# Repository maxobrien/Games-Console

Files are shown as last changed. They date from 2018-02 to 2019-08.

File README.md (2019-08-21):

# Games Console Project - Max O'Brien
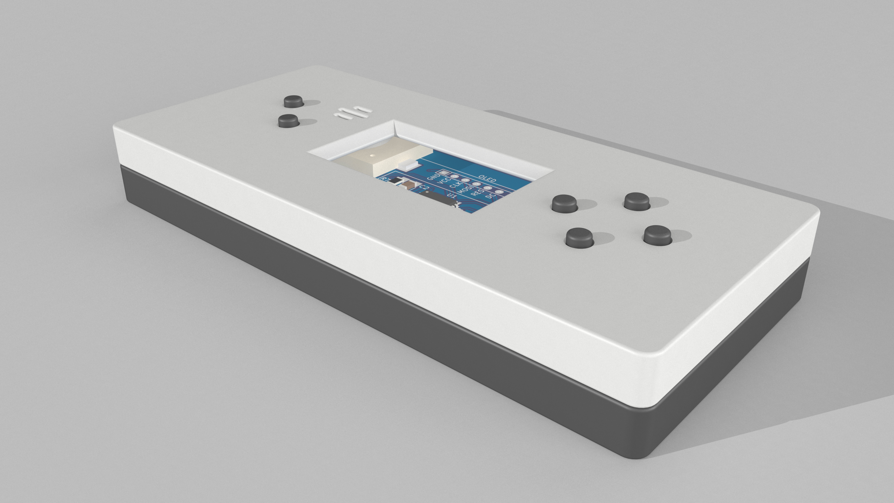
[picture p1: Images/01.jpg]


Above are all the files for my games console project.

## PCB Design Files
The PCB was originally designed in <a href="http://kicad-pcb.org/">KiCad 4.0.7</a> however other versions may still be able to open it. The board is a 2-layered design that can easily be manufactured at most places if that is what you wish to do.

**UPDATE** As of KiCad version 5.0 the board can still be opened however, you will need to run the automatic schematic symbol converter.

## STL Files
These files are for the enclosure of the games console. They fit the PCB supplied and so would need to be changed if you changed the dimensions of the board. If you are making your own then they can just be printed on a normal 3D printer, however, I would suggest you choose settings, and material, that will yield the highest quality detail as some of the model contains fine details. I chose black and white (as seen in the above render) and also printed it in SLS nylon.

## The Code
The code is written in the Arduino IDE. This means to open it, you will need the <a href="https://www.arduino.cc/en/Main/Software">Arduino IDE</a>. Before loading the code onto the micro, you will first have to burn a bootloader. Some guides to do this are listed below, however, doing your own research may yield better results.

- https://www.arduino.cc/en/Hacking/Bootloader
- https://learn.adafruit.com/ftdi-friend/programming-the-arduino-bootloader
- http://www.gammon.com.au/breadboard

Once the bootloader has be burned, you can upload the code. To do this, ensure your programmer is connected with a USB cable and open up the code in the Arduino IDE. Also ensure that the programmer is correctly connected to the programming header (Bottom Left) on the PCB. Check that all 5 tabs can be seen along the top labelled; "Main", "Breakout", "Menu", "pong" and "Settings". Next go to 'Tools > Board' and ensure 'Arduino/Genuino Uno' is selected. Then go to 'Tools > Port' and select the right port for your programmer. Finally, select 'Sketch > Upload Using Programmer'. Once this operation is complete, you should have a working games console!

## Console Renders
<details>
  <summary>Click to show renders</summary>
  
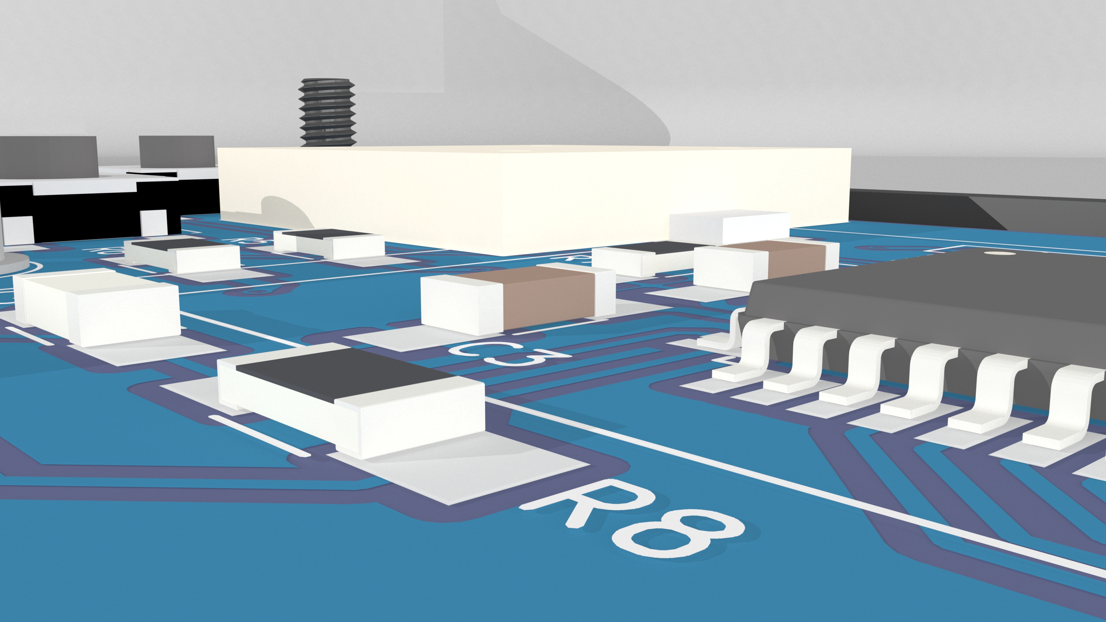
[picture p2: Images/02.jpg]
  
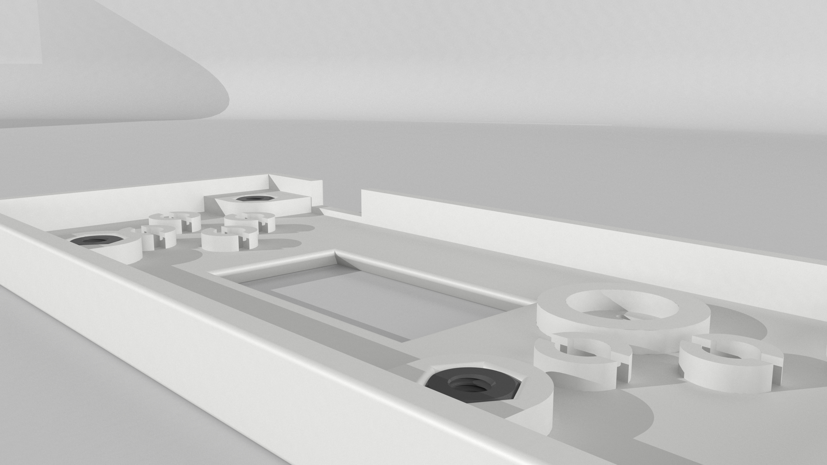
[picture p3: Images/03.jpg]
  
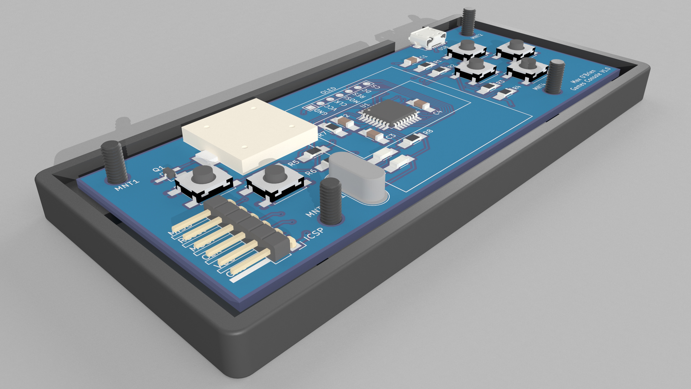
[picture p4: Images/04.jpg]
  
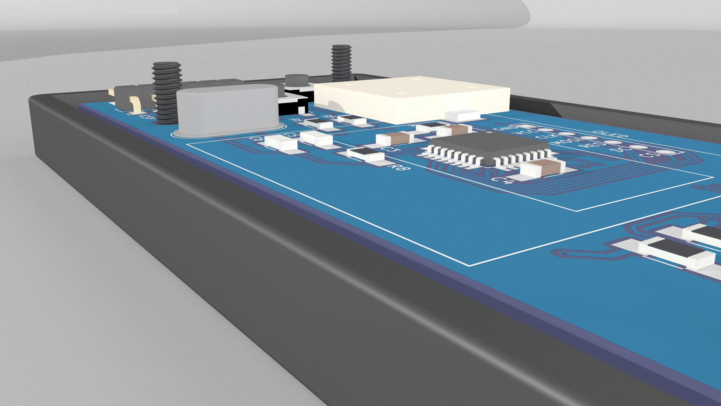
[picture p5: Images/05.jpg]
  
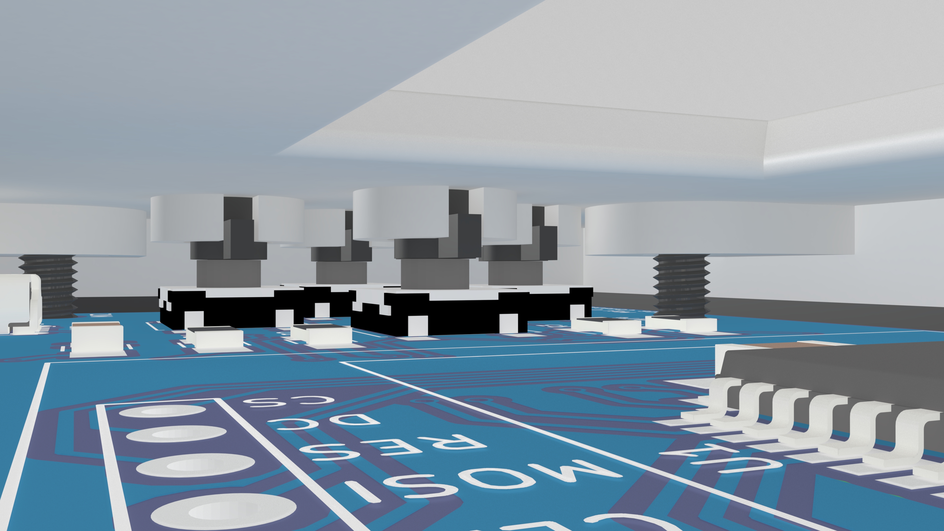
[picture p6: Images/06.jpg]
  
</details>

## Required Libraries for Code
- U8g2

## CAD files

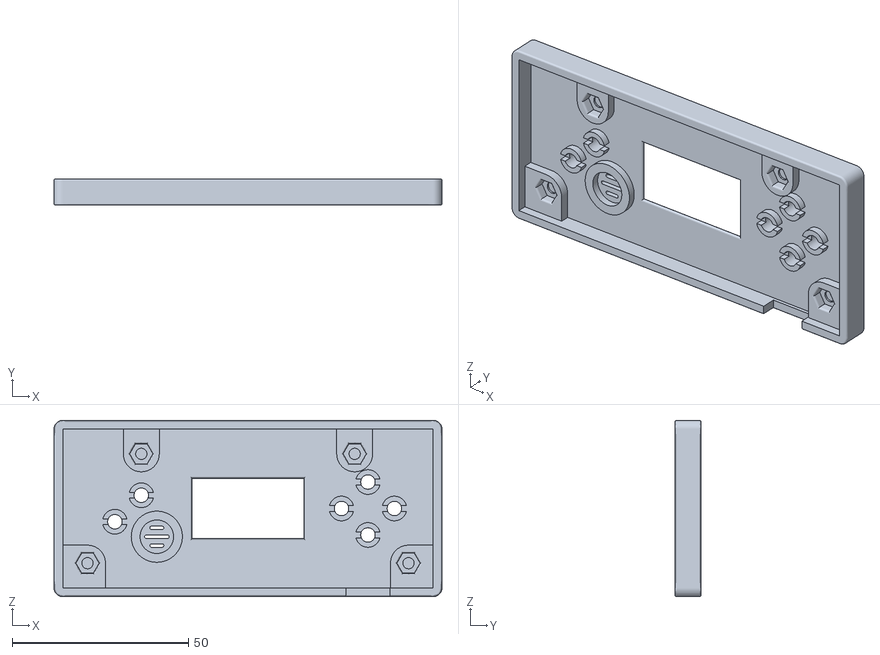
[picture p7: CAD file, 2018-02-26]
STL/Top (White).stl
110.0 x 7.50 x 50.0

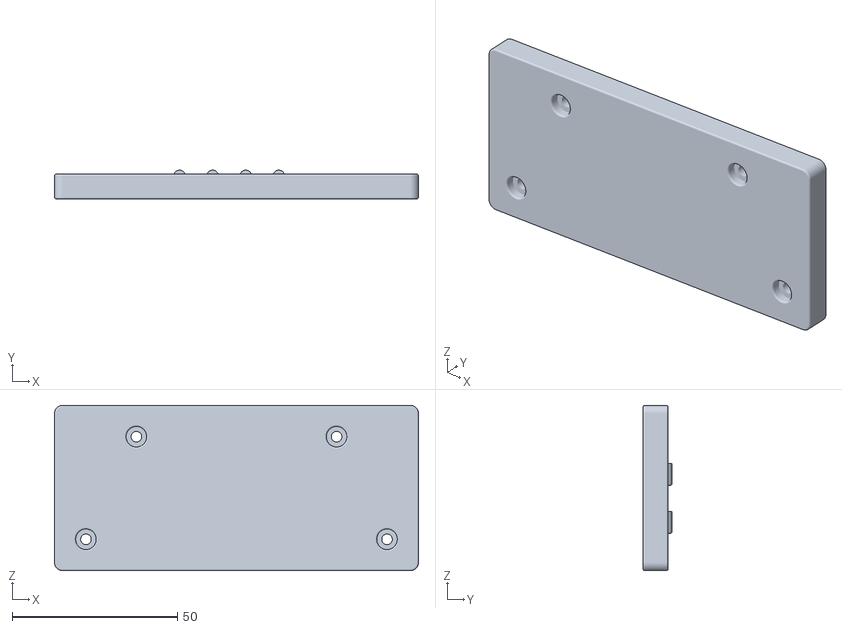
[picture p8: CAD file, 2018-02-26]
STL/Base and Buttons (Black).stl
110.0 x 8.70 x 50.0

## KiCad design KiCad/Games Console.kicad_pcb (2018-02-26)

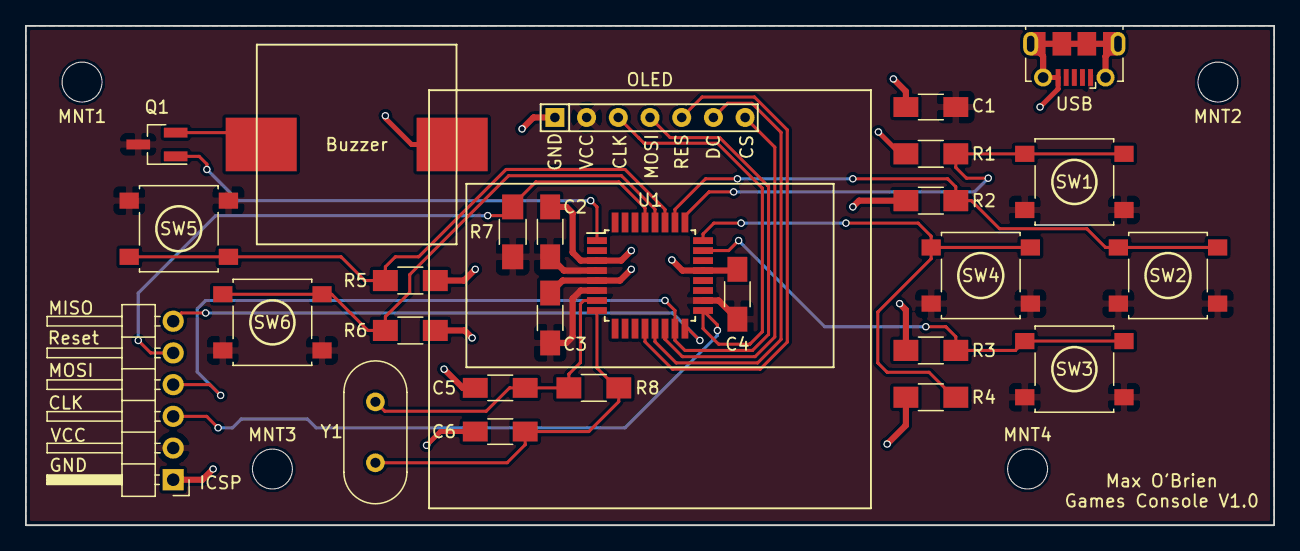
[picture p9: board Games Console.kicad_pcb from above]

Board: 2 copper layers, 100.0 x 40.0 mm, 31 parts (0 on the bottom side), 19 nets.

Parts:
Buzzer: Buzzer; KMTG1603_Piezo_Buzzer
C1, C2, C3, C4: 0.1uF; C_1206_HandSoldering
C5, C6: 18pF; C_1206_HandSoldering
ICSP: Conn_01x06_Male; Pin_Header_Angled_1x06_Pitch2.54mm
MNT1, MNT2, MNT3, MNT4: MountingHole_3.2mm_M3
OLED: Conn_01x07_Male; OLED-1.3
Q1: 2N7002; SOT-23_Handsoldering
R1, R2, R3, R4, R5, R6, R7: 10k; R_1206_HandSoldering
R8: 1M; R_1206_HandSoldering
SW1, SW2, SW3, SW4, SW5, SW6: SW_Push; SW_SPST_B3S-1000
U1: ATMEGA328P-AU; TQFP-32_7x7mm_Pitch0.8mm
USB: USB_OTG; USB_Micro-B_Molex-105017-0001
Y1: 16mHz; Crystal_HC49-4H_Vertical

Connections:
+5V: C1.1, C2.1, C3.1, C4.1, ICSP.2, OLED.2, Q1.3, R7.2, SW1.1, SW2.1, SW3.1, SW4.1, SW5.1, SW6.1, U1.4, U1.6, U1.18, USB.1
BUZZER: Q1.1, U1.1
CLK: ICSP.3, OLED.3, U1.17
CS: OLED.7, U1.14
DC: OLED.6, U1.13
DOWN: R3.2, SW3.2, U1.23
GND: Buzzer.2, C1.2, C2.2, C3.2, C4.2, C5.1, C6.1, ICSP.1, OLED.1, R1.1, R2.1, R3.1, R4.1, R5.1, R6.1, U1.3, U1.5, U1.21, USB.5, USB.6
LEFT: R4.2, SW4.2, U1.24
MENU: R5.2, SW5.2, U1.27
MISO: ICSP.6, U1.16
MOSI: ICSP.4, OLED.4, U1.15
unnamed: Buzzer.1, Q1.2
unnamed: C5.2, R8.1, U1.7, Y1.1
unnamed: C6.2, R8.2, U1.8, Y1.2
unnamed: ICSP.5, R7.1, U1.29
RES: OLED.5, U1.12
RIGHT: R2.2, SW2.2, U1.26
SELECT: R6.2, SW6.2, U1.28
UP: R1.2, SW1.2, U1.25

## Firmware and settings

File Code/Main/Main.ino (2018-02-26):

/* Include definitions */
#include <Arduino.h>
#include <SPI.h>
#include <U8g2lib.h>

//Screen constructor
U8G2_SH1106_128X64_NONAME_1_4W_HW_SPI u8g2(/*Rotation=*/ U8G2_R0, /*cs=*/ 10, /*dc=*/ 9, /*Reset=*/ 8);



/* ===================================================== */
/* GLOBAL VARIABLE DEFINITIONS */

//Value for which 'screen' we should draw - we should starton the menu by default
int currentScreen = 1;
/* Possilbe Values
    1 = Menu
    2 = Pong
    3 = Breakout
    4 = Settings
*/

//Assigning currentMillis to start at 0
unsigned long currentMillis = 0;

//Button inputs
const int leftBtn = A1;
const int upBtn = A2;
const int rightBtn = A3;
const int downBtn = A0;
const int menuBtn = A4;
const int selectBtn = A5;

//Previous button inputs
int prevLeftBtnState = 0;
int prevUpBtnState = 0;
int prevRightBtnState = 0;
int prevDownBtnState = 0;
int prevMenuBtnState = 0;
int prevSelectBtnState = 0;

//Loading 'apps'
bool menuLoaded = false;
bool pongLoaded = false;
bool breakoutLoaded = false;
bool settingsLoaded = false;

//Game difficulty
int difficulty = 3;
/* Possible Values
    2 = Easy
    3 = Medium
    5 = Hard
*/

int buzzerFreq = 450;

const int randomPin = 7;

const int buzzerPin = 3;

unsigned long previousSelectMillis = 0;

bool playedPowerMelody = false;
bool playedLoseMelody = false;
bool playedWinMelody = false;

/* ===================================================== */

bool breakoutSetup = false;

void setup() {
  //The main line to initialise the display
  u8g2.begin();

  //Set the font for the display, this will be the only font used
  u8g2.setFont(u8g2_font_6x12_tr);

  pinMode(leftBtn, INPUT);
  pinMode(upBtn, INPUT);
  pinMode(rightBtn, INPUT);
  pinMode(downBtn, INPUT);
  pinMode(menuBtn, INPUT);
  pinMode(selectBtn, INPUT);

  pinMode(buzzerPin, OUTPUT);


  
}

void loop() {

  if (playedPowerMelody == false) {
    powerMelody();
  }

  if ((digitalRead(menuBtn) == HIGH) && (prevMenuBtnState != digitalRead(menuBtn))) {
    currentScreen = 1;
  }
  prevMenuBtnState = digitalRead(menuBtn);

  //Storing the current millis so that the various apps can use it
  currentMillis = millis();

  u8g2.firstPage(); //Required line

  switch (currentScreen) {
    case 1: //Main Menu
      do {
        if (menuLoaded == false) {
          loadMenu();
        }
        drawMenu(); //Draw the main menu
        menuButtons(); //Check for button presses in the menu 'screen'
        breakoutSetup = false;

        pongLoaded = false;
        breakoutLoaded = false;
        settingsLoaded = false;
      } while ( u8g2.nextPage() );
      break;

    case 2: //Pong
      do {
        if (pongLoaded == false) {
          loadPong();
        }
        drawPong(); //Draw the pong game
        pongButtons(); //Check the buttons inputs when playing pong

        menuLoaded = false;
        breakoutLoaded = false;
        settingsLoaded = false;
      } while ( u8g2.nextPage() );
      break;

    case 3: //Breakout
      do {
        if (breakoutLoaded == false) {
          loadBreakout();
        }
        //If we want to play breakout and we haven't set up the function yet, then we should. This will only run once per time we want to play.
        if (breakoutSetup == false) {
          setupBreakout(); //Run the setup of breakout once everytime we want to play;
        }
        drawBreakout(); //Draw the main menu
        breakoutButtons(); //Check the buttons inputs when playing breakout

        menuLoaded = false;
        pongLoaded = false;
        settingsLoaded = false;
      } while ( u8g2.nextPage() );
      break;

    case 4: //Settings
      do {
        if (settingsLoaded == false) {
          loadSettings();
        }
        drawSettings();
        settingsButtons();

        menuLoaded = false;
        pongLoaded = false;
        breakoutLoaded = false;
      } while ( u8g2.nextPage() );
      break;

    default:
      //If all else fails, just draw the menu
      do {
        drawMenu(); //Draw the main menu
        menuButtons(); //Check for button presses in the menu 'screen'
        breakoutSetup = false;

        pongLoaded = false;
        breakoutLoaded = false;
        settingsLoaded = false;
      } while ( u8g2.nextPage() );
      break;
  }
}

void powerMelody() {
  tone(buzzerPin, 261.63, 272.727);
  delay(272.727);
  tone(buzzerPin, 440.00, 68.182);
  delay(68.182 + 68.182);
  tone(buzzerPin, 329.63, 136.364);
  delay(68.182 + 136.364);
  tone(buzzerPin, 246.94, 272.727);
  delay(272.727);
  tone(buzzerPin, 261.63, 272.727);
  delay(272.727);
  playedPowerMelody = true;
}

void loseMelody() {
  tone(buzzerPin, 233.08, (136.364 * 3));
  delay((136.364 * 3) + 136.364);
  tone(buzzerPin, 220.00, (136.364 * 3));
  delay((136.364 * 3) + 136.364);
  tone(buzzerPin, 207.65, (136.364 * 3));
  delay((136.364 * 3) + 136.364);
  tone(buzzerPin, 196.00, (545.455 + 272.727));
  delay(545.455 + 272.727);
  playedLoseMelody = true;
}

void winMelody() {
  tone(buzzerPin, 261.63, 272.727);
  delay(272.727);
  tone(buzzerPin, 329.63, 272.727);
  delay(272.727);
  tone(buzzerPin, 392.00, 272.727);
  delay(272.727);
  tone(buzzerPin, 523.25, (136.364 * 3));
  delay(136.364 * 3);
  playedWinMelody = true;
}

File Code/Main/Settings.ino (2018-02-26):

/* ===================================================== */
/* SETTINGS DEFINITIONS */

const int settings_menuItems = 2; //Number of menu items - includes 0

/* Select Box */
const int settings_selectBoxPosY = 18; //Y pos for highlight box
const int settings_selectBoxHeight = 12; //Height of the highlight box

int settings_currentMenuItem = 0; //Keep track of currently selected item - start at first

/* ===================================================== */

void loadSettings() {
  settings_currentMenuItem = 0;
  settingsLoaded = true;
}

void drawSettings() {
  u8g2.drawStr((64 - (u8g2.getStrWidth("Settings") / 2)), 12, "Settings");
  u8g2.drawHLine(0, 15, 128); //Draw line under title

  u8g2.setFontMode(1); //Transparent font mode
  u8g2.setDrawColor(1); //Box fill colour

  //Draw out the hightlight box
  u8g2.drawBox(0, (settings_selectBoxPosY + (settings_currentMenuItem * settings_selectBoxHeight)), 128, settings_selectBoxHeight);

  //Give the text XOR colour mode - the box being over the text will change it's colour
  u8g2.setDrawColor(2);

  //Itterate over all the settings and wirte them out
  for (int i = 0; i <= settings_menuItems; i++) {
    switch (i) {
      case 0: //Difficulty
        u8g2.drawStr(2, (15 + ((i + 1) * 12)), "Difficulty");

        switch (difficulty) {
          case 2:
            u8g2.drawStr((126 - (u8g2.getStrWidth("Easy"))), (15 + ((i + 1) * 12)), "Easy");
            break;

          case 3:
            u8g2.drawStr((126 - (u8g2.getStrWidth("Medium"))), (15 + ((i + 1) * 12)), "Medium");
            break;

          case 5:
            u8g2.drawStr((126 - (u8g2.getStrWidth("Hard"))), (15 + ((i + 1) * 12)), "Hard");
            break;

          default:
            break;
        }

        break;

      case 1: //Frequency
        u8g2.drawStr(2, (15 + ((i + 1) * 12)), "Frequency");

        switch (buzzerFreq) {
          case 250:
            u8g2.drawStr((126 - (u8g2.getStrWidth("250 Hz"))), (15 + ((i + 1) * 12)), "250 Hz");
            break;

          case 450:
            u8g2.drawStr((126 - (u8g2.getStrWidth("450 Hz"))), (15 + ((i + 1) * 12)), "450 Hz");
            break;

          case 550:
            u8g2.drawStr((126 - (u8g2.getStrWidth("550 Hz"))), (15 + ((i + 1) * 12)), "550 Hz");
            break;

          case 750:
            u8g2.drawStr((126 - (u8g2.getStrWidth("750 Hz"))), (15 + ((i + 1) * 12)), "750 Hz");
            break;

          case 1150:
            u8g2.drawStr((126 - (u8g2.getStrWidth("1150 Hz"))), (15 + ((i + 1) * 12)), "1150 Hz");
            break;

          default:
            break;
        }

        break;

      case 2: //Back button
        u8g2.drawStr(2, (15 + ((i + 1) * 12)), "<- Back");

      default:
        break;
    }
  }
}

void settingsButtons() {
  //Check to see if we are on the menu screen. If we are then we want to check the value of the buttons
  if (currentScreen == 4) {

    //UP
    if ((digitalRead(upBtn) == HIGH) && (prevUpBtnState != digitalRead(upBtn))) {
      settings_currentMenuItem -= 1;
      tone(buzzerPin, buzzerFreq, 100);
    }

    //LEFT
    if ((digitalRead(leftBtn) == HIGH) && (prevLeftBtnState != digitalRead(leftBtn))) {
      leftSettingsOptions();
      tone(buzzerPin, buzzerFreq, 100);
    }

    //RIGHT
    if ((digitalRead(rightBtn) == HIGH) && (prevRightBtnState != digitalRead(rightBtn))) {
      rightSettingsOptions();
      tone(buzzerPin, buzzerFreq, 100);
    }
    
    //DOWN
    if ((digitalRead(downBtn) == HIGH) && (prevDownBtnState != digitalRead(downBtn))) {
      settings_currentMenuItem += 1;
      tone(buzzerPin, buzzerFreq, 100);
    }

    //SELECT
    if ((digitalRead(selectBtn) == HIGH) && (prevSelectBtnState != digitalRead(selectBtn))) {
      rightSettingsOptions();
      tone(buzzerPin, buzzerFreq, 100);
    }

    if (settings_currentMenuItem < 0) {
      settings_currentMenuItem = settings_menuItems;
    } else if (settings_currentMenuItem > settings_menuItems) {
      settings_currentMenuItem = 0;
    }

    prevLeftBtnState = digitalRead(leftBtn);
    prevUpBtnState = digitalRead(upBtn);
    prevRightBtnState = digitalRead(rightBtn);
    prevDownBtnState = digitalRead(downBtn);
    prevSelectBtnState = digitalRead(selectBtn);
  }
}
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

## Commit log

2018-02-26 Added KiCad PCB files
    [Games Console.kicad_pcb, Games Console.sch]
2018-02-26 Added STL files for printing
    [Base and Buttons (Black).stl, Top (White).stl]
2018-02-26 Added Arduino Code
2019-08-21 Added gerber files
2019-08-21 Update for KiCad 5.0
